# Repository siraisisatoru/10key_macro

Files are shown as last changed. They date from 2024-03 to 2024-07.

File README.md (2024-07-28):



# 10key_macro

A DIY project building an Arduino-based macro keyboard with a 4-bit switch and rotary encoder.

# Background

<!-- The reason for creating this project/ -->
<!-- the why this project is important -->

A number of years ago, I used to learn PIC18 microcontroller and programming using `assembly language`. One of the concepts is using a polling technique to get the button response. Since then I have conducted deep research into designing customized keyboards. Despite there being a huge number of existing projects on the internet, I did want to implement them myself.

# Description

<!-- Describe what it is and what it is included -->

This project mainly consists of four parts. Circuit design, enclosure design, Arduino coding, Python coding.

1. Circuit design

The circuit schematic was built on the EasyEDA platform and is now being ported to KiCAD.



The circuit consists of a microcontroller, 10 cherry keys with 2812 LEDs, an IC74165, an EEPROM AT24C64, a rotary encoder and a 4-bit toggle switch.

By following the schematic, the main circuit was built on a proof board and connected to keys and LEDs through wires.

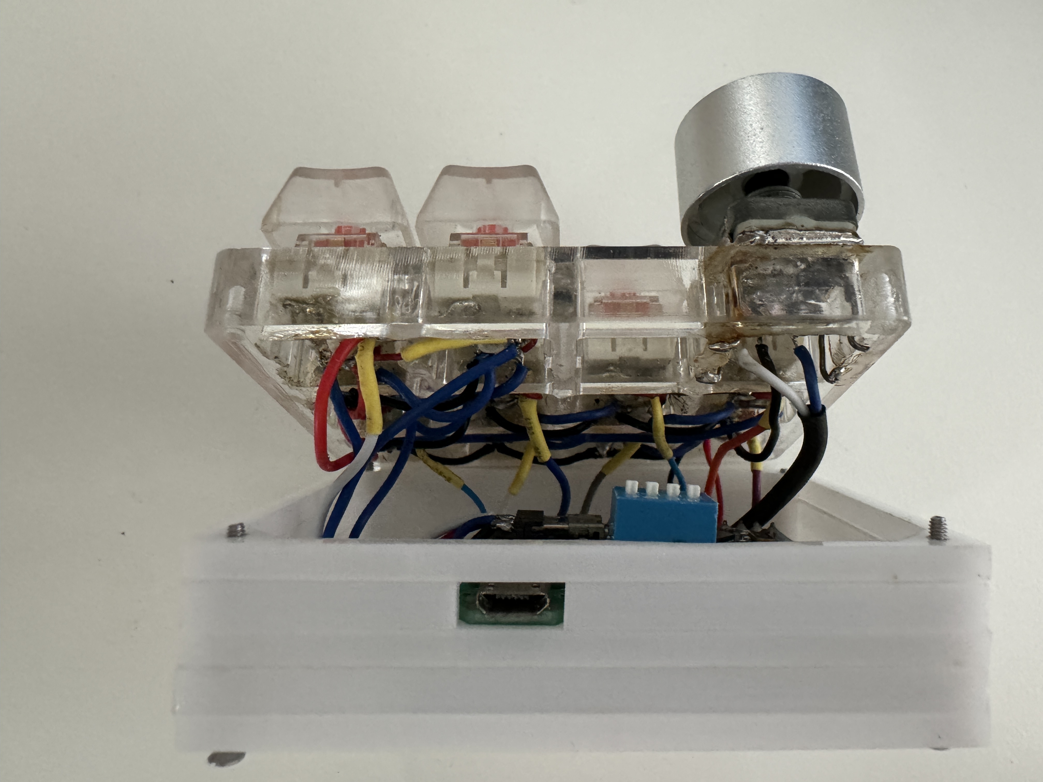
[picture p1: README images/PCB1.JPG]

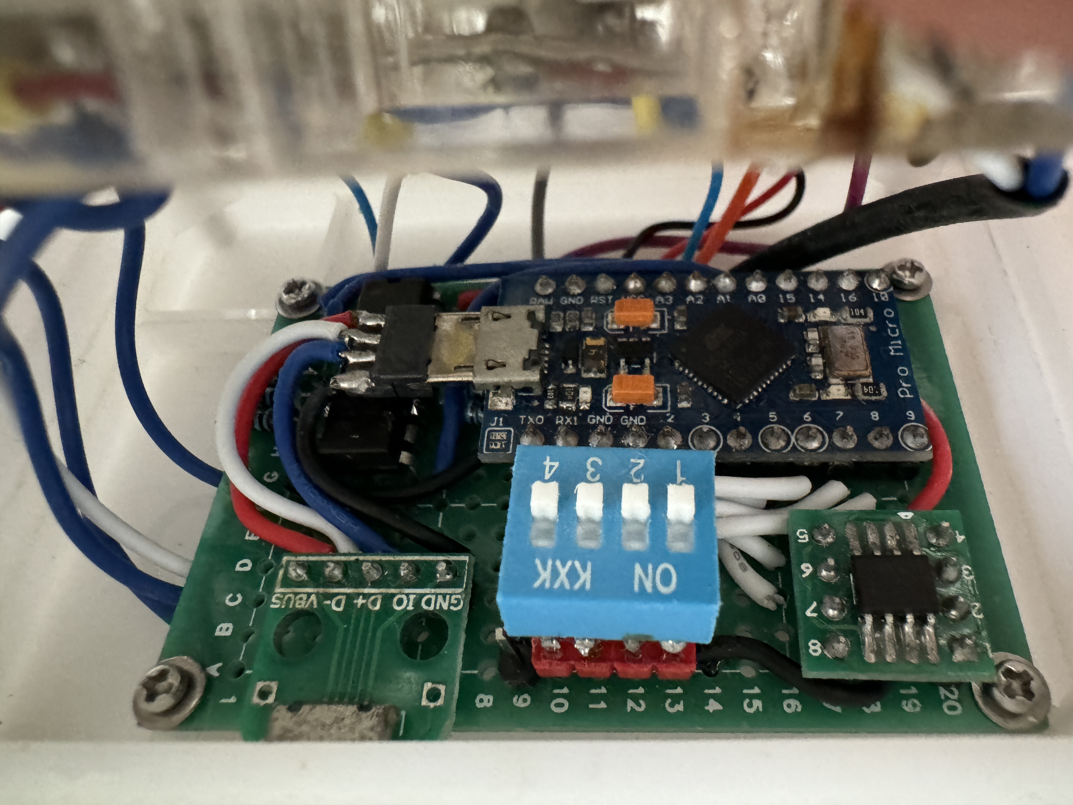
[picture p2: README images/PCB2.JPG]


2. Enclosure design

The enclosure is designed for multiple layers of 4.5mm and 4mm acrylic. The enclosure however begins to fall apart due to aging. A 3D-printed version designed will be reproduced later.

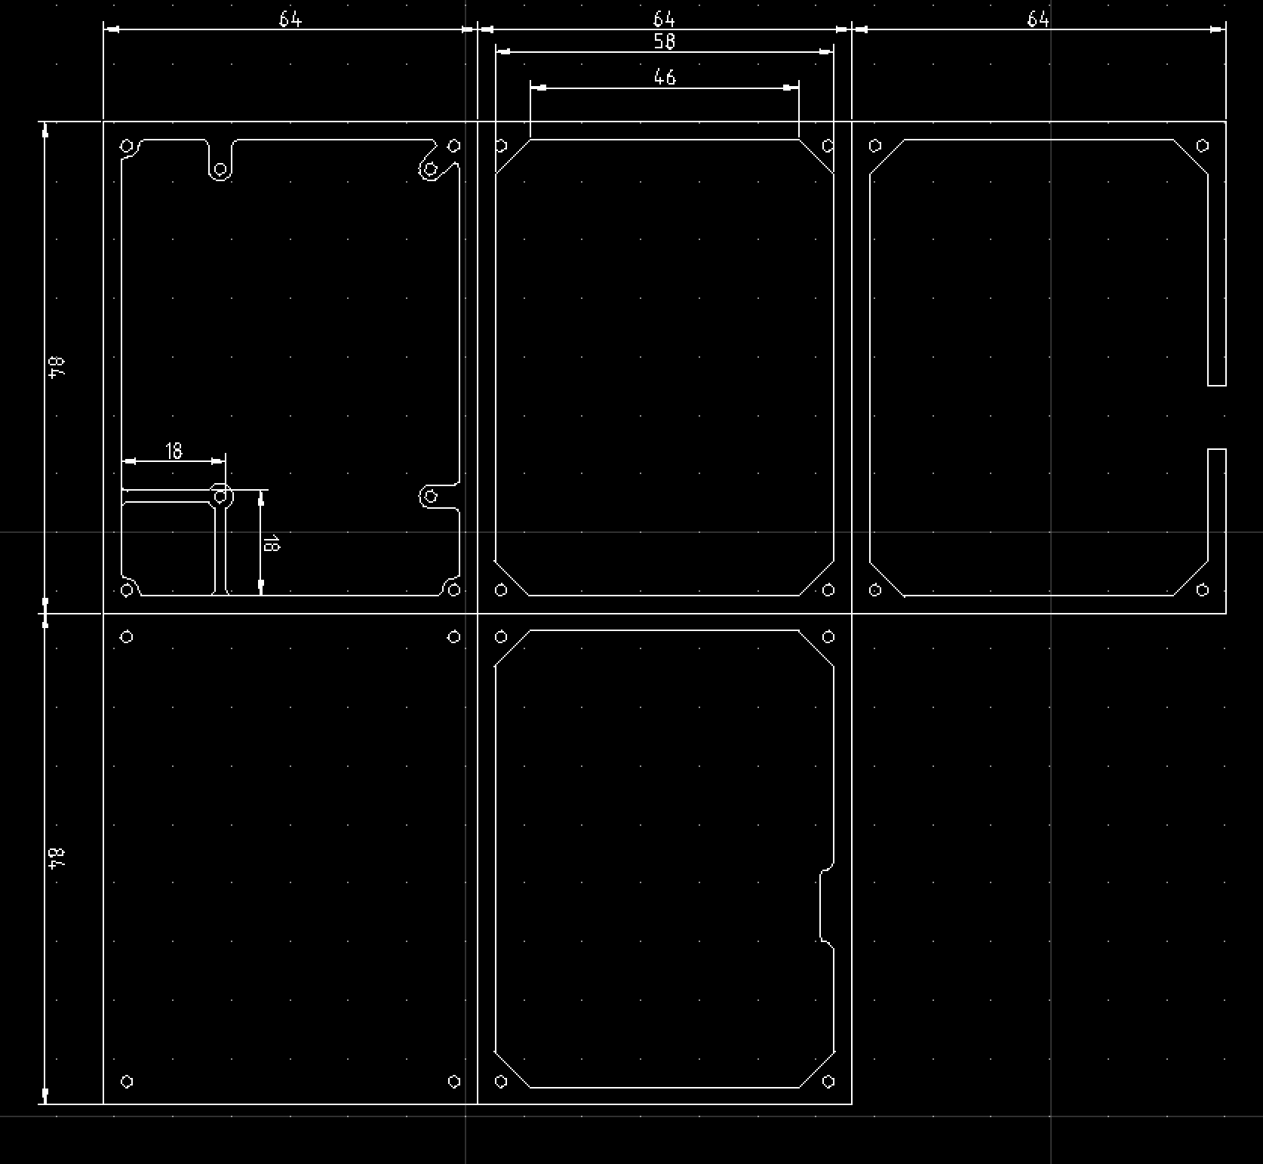
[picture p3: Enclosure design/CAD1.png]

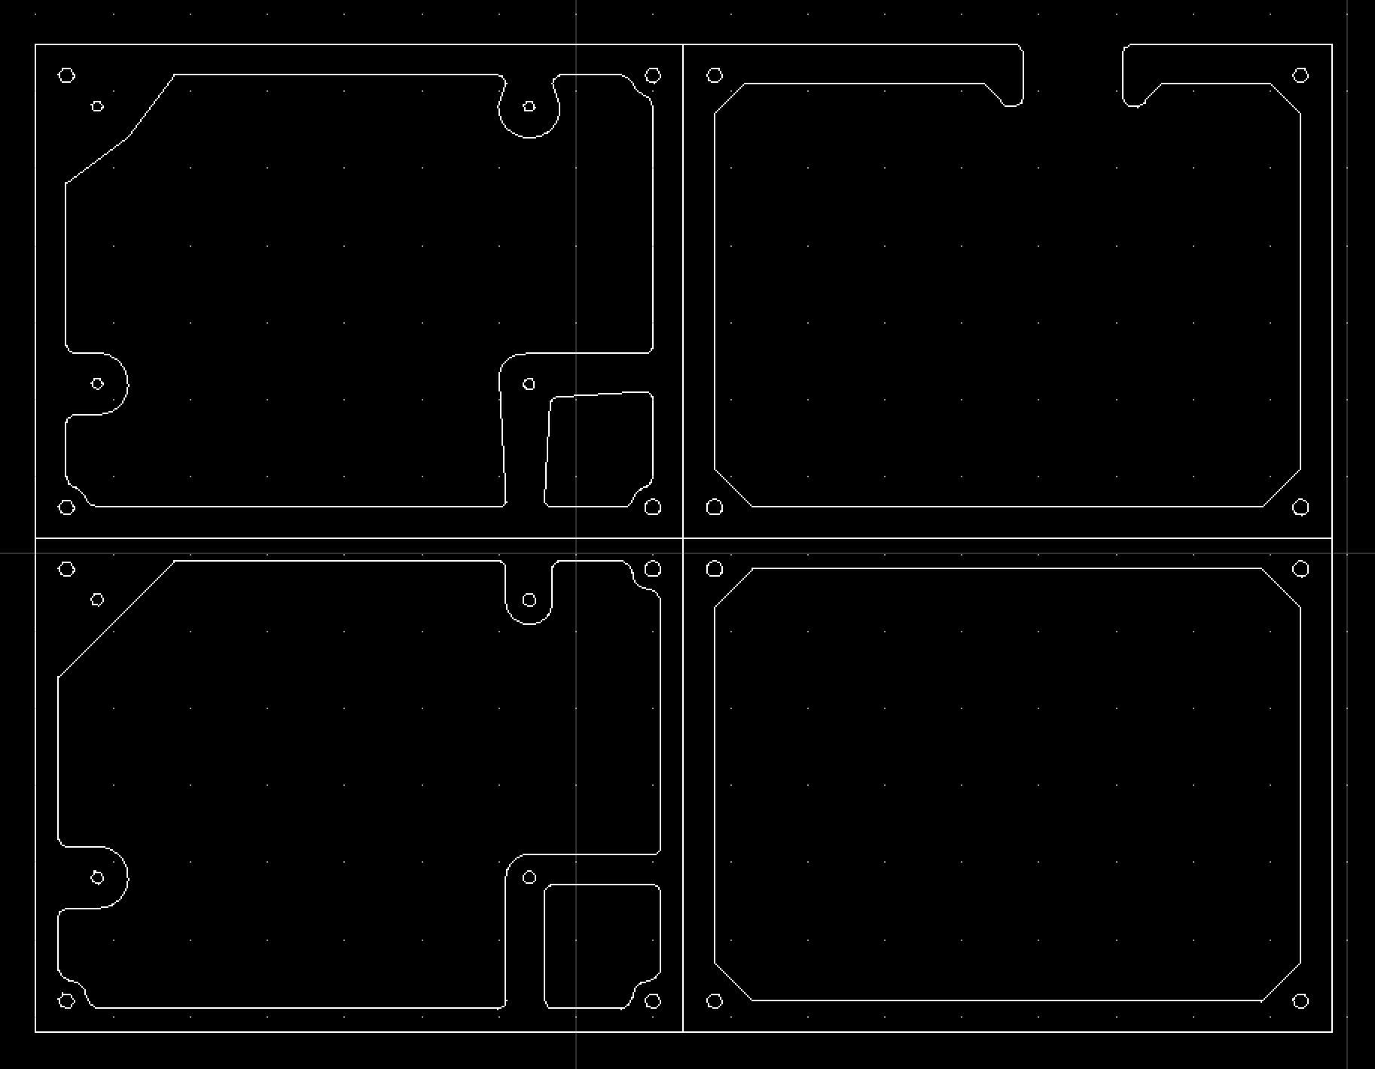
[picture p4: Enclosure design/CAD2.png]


3. Arduino coding

The fundamental idea of the Arduino code design is framing. There are two parts of the Arduino code structure, `setup` and `loop`. I initialize all objects as well as pin I/O in `setup` section; and perform LED and key checks in the loop.

```mermaid
flowchart TD

    subgraph setup
        direction LR

        A[Create objects]-->B[`memMaster` and <br> `panelMaster` init]
        B --> C[Begin initialise <br> keyboard ]
        C --> D[Add rotary encoder <br> to interrupts]
        D --> E[Wait for Serial port]
        E --> E
        E --> F[Wellcome loop]
    end

    subgraph loop
        direction LR

        G[State switch]

        G --> H[state 0]
        G --> I[state 1-8]
        G --> J[state 13]
        G --> K[state 14]
        G --> L[state 15]

        H-->M[LEDShowTick]
        M-->S

        I-->N[monitorKeys]
        N-->O[LEDShowTick]
        O-->S

        J-->P[flush EEPROM]
        P-->S

        K-->Q[print EEPROM]
        Q-->S

        L-->R[load EEPROM <br> from python]
        R-->S

        S[check state and <br> update key config]-->G

    end
    setup --> loop
```

The state is determined by the toggle switch which is capable of 16 values (0 -> 15) and additional functions can be added through the addition of new cases to the `switch`.

| swich pattern | code | feature | description |
| :---: | :--: | :---: | :---: |
| 0000 |  0 | LED display | Complete LED loop through all supported LED effects |
| 0001 |  1 | mode 1 | |
| 0010 |  2 | mode 2 | |
| 0011 |  3 | mode 3 | |
| 0100 |  4 | mode 4 | |
| 0101 |  5 | mode 5 | |
| 0110 |  6 | mode 6 | |
| 0111 |  7 | mode 7 | |
| 1000 |  8 | mode 8 | |
| 1101 |  13  | Flush EEPROM <br> (need to modify Arduino code) | Replace all values in the EEPROm by 0xFF |
| 1110 |  14  | Print Key map | Automatically print whole EEPROM content <br> `-` represents 0xFF |
| 1111 |  15  | Load key map from PC | Enter this mode, use Python to pass mapping json to Arduino |

4. Python coding

To configure each key output in each mode, a predefined JSON file is created and can be loaded to EEPROM. Arduino will load the specific chunk from EEPROM to update each key config.

| Key in object | Description | Example |
| :---: | :---: | :---: |
| Mode | `"mode-xxxx"` <br> where xxxx is the binary representation of the state | `"mode-0001"` |
| Key index | From `"0"` to `"9"` represents the key index of the keyboard | `"0"` |
| default string `"str"` | `"mx string test - y"` where x is the mode from `1` to `8` and <br> y is the key index | `"m1 string test - 1"` |
| default key <br> binding list `"list"` | The list of keybinding that will be `pressed` all in once | `["KEY_LEFT_GUI", "r", null]` |
| default key mode `"mode"` | `1` means print string, `0` means press key binding in the list and `2` means press and hold | `1` |

<details>
<summary> Default configuration JSON file</summary>

```json
{
    "mode-0001": {
        "0": {
            "str": "m1 string test - 0, intentionally make a long string for testing",
            "list": ["KEY_DELETE", null, null],
            "mode": 1
        },
        "1": {
            "str": "m1 string test - 1",
            "list": ["KEY_LEFT_GUI", "r", null],
            "mode": 0
        },
        "2": {
            "str": "m1 string test - 2",
            "list": ["KEY_DELETE", null, null],
            "mode": 0
        },
        "3": {
            "str": "m1 string test - 3",
            "list": [null, null, null],
            "mode": 1
        },
        "4": {
            "str": "m1 string test - 4",
            "list": [null, null, null],
            "mode": 1
        },
        "5": {
            "str": "m1 string test - 5",
            "list": [null, null, null],
            "mode": 1
        },
        "6": {
            "str": "m1 string test - 6",
            "list": [null, null, null],
            "mode": 1
        },
        "7": {
            "str": "m1 string test - 7",
            "list": [null, null, null],
            "mode": 1
        },
        "8": {
            "str": "m1 string test - 8",
            "list": [null, null, null],
            "mode": 1
        },
        "9": {
            "str": "m1 string test - 9",
            "list": [null, null, null],
            "mode": 1
        }
    },
    "mode-0010": {
        "0": {
            "str": "",
            "list": [null, null, null],
            "mode": 2
        },
        "1": {
            "str": "m2 string test - 1",
            "list": [null, null, null],
            "mode": 0
        },
        "2": {
            "str": "m2 string test - 2",
            "list": ["KEY_LEFT_GUI", "s", null],
            "mode": 2
        },
        "3": {
            "str": "m2 string test - 3",
            "list": ["KEY_LEFT_GUI", "x", null],
            "mode": 0
        },
        "4": {
            "str": "m2 string test - 4",
            "list": ["KEY_LEFT_SHIFT", null, null],
            "mode": 2
        },
        "5": {
            "str": "m2 string test - 5",
            "list": ["KEY_UP_ARROW", null, null],
            "mode": 0
        },
        "6": {
            "str": "m2 string test - 6",
            "list": ["KEY_LEFT_GUI", "f", null],
            "mode": 0
        },
        "7": {
            "str": "m2 string test - 7",
            "list": ["KEY_LEFT_GUI", "v", null],
            "mode": 0
        },
        "8": {
            "str": "m2 string test - 8",
            "list": ["KEY_LEFT_GUI", "c", null],
            "mode": 0
        },
        "9": {
            "str": "m2 string test - 9",
            "list": ["KEY_DOWN_ARROW", null, null],
            "mode": 0
        }
    },
    "mode-0011": {
        "0": {
            "str": "m3 string test - 0",
            "list": [null, null, null],
            "mode": 1
        },
        "1": {
            "str": "m3 string test - 1",
            "list": [null, null, null],
            "mode": 1
        },
        "2": {
            "str": "m3 string test - 2",
            "list": [null, null, null],
            "mode": 1
        },
        "3": {
            "str": "m3 string test - 3",
            "list": [null, null, null],
            "mode": 1
        },
        "4": {
            "str": "m3 string test - 4",
            "list": [null, null, null],
            "mode": 1
        },
        "5": {
            "str": "m3 string test - 5",
            "list": [null, null, null],
            "mode": 1
        },
        "6": {
            "str": "m3 string test - 6",
            "list": [null, null, null],
            "mode": 1
        },
        "7": {
            "str": "m3 string test - 7",
            "list": [null, null, null],
            "mode": 1
        },
        "8": {
            "str": "m3 string test - 8",
            "list": [null, null, null],
            "mode": 1
        },
        "9": {
            "str": "m3 string test - 9",
            "list": [null, null, null],
            "mode": 1
        }
    },
    "mode-0100": {
        "0": {
            "str": "m4 string test - 0",
            "list": [null, null, null],
            "mode": 1
        },
        "1": {
            "str": "m4 string test - 1",
            "list": [null, null, null],
            "mode": 1
        },
        "2": {
            "str": "m4 string test - 2",
            "list": [null, null, null],
            "mode": 1
        },
        "3": {
            "str": "m4 string test - 3",
            "list": [null, null, null],
            "mode": 1
        },
        "4": {
            "str": "m4 string test - 4",
            "list": [null, null, null],
            "mode": 1
        },
        "5": {
            "str": "m4 string test - 5",
            "list": [null, null, null],
            "mode": 1
        },
        "6": {
            "str": "m4 string test - 6",
            "list": [null, null, null],
            "mode": 1
        },
        "7": {
            "str": "m4 string test - 7",
            "list": [null, null, null],
            "mode": 1
        },
        "8": {
            "str": "m4 string test - 8",
            "list": [null, null, null],
            "mode": 1
        },
        "9": {
            "str": "m4 string test - 9",
            "list": [null, null, null],
            "mode": 1
        }
    },
    "mode-0101": {
        "0": {
            "str": "m5 string test - 0",
            "list": [null, null, null],
            "mode": 1
        },
        "1": {
            "str": "m5 string test - 1",
            "list": [null, null, null],
            "mode": 1
        },
        "2": {
            "str": "m5 string test - 2",
            "list": [null, null, null],
            "mode": 1
        },
        "3": {
            "str": "m5 string test - 3",
            "list": [null, null, null],
            "mode": 1
        },
        "4": {
            "str": "m5 string test - 4",
            "list": [null, null, null],
            "mode": 1
        },
        "5": {
            "str": "m5 string test - 5",
            "list": [null, null, null],
            "mode": 1
        },
        "6": {
            "str": "m5 string test - 6",
            "list": [null, null, null],
            "mode": 1
        },
        "7": {
            "str": "m5 string test - 7",
            "list": [null, null, null],
            "mode": 1
        },
        "8": {
            "str": "m5 string test - 8",
            "list": [null, null, null],
            "mode": 1
        },
        "9": {
            "str": "m5 string test - 9",
            "list": [null, null, null],
            "mode": 1
        }
    },
    "mode-0110": {
        "0": {
            "str": "m6 string test - 0",
            "list": [null, null, null],
            "mode": 1
        },
        "1": {
            "str": "m6 string test - 1",
            "list": [null, null, null],
            "mode": 1
        },
        "2": {
            "str": "m6 string test - 2",
            "list": [null, null, null],
            "mode": 1
        },
        "3": {
            "str": "m6 string test - 3",
            "list": [null, null, null],
            "mode": 1
        },
        "4": {
            "str": "m6 string test - 4",
            "list": [null, null, null],
            "mode": 1
        },
        "5": {
            "str": "m6 string test - 5",
            "list": [null, null, null],
            "mode": 1
        },
        "6": {
            "str": "m6 string test - 6",
            "list": [null, null, null],
            "mode": 1
        },
        "7": {
            "str": "m6 string test - 7",
            "list": [null, null, null],
            "mode": 1
        },
        "8": {
            "str": "m6 string test - 8",
            "list": [null, null, null],
            "mode": 1
        },
        "9": {
            "str": "m6 string test - 9",
            "list": [null, null, null],
            "mode": 1
        }
    },
    "mode-0111": {
        "0": {
            "str": "m7 string test - 0",
            "list": [null, null, null],
            "mode": 1
        },
        "1": {
            "str": "m7 string test - 1",
            "list": [null, null, null],
            "mode": 1
        },
        "2": {
            "str": "m7 string test - 2",
            "list": [null, null, null],
            "mode": 1
        },
        "3": {
            "str": "m7 string test - 3",
            "list": [null, null, null],
            "mode": 1
        },
        "4": {
            "str": "m7 string test - 4",
            "list": [null, null, null],
            "mode": 1
        },
        "5": {
            "str": "m7 string test - 5",
            "list": [null, null, null],
            "mode": 1
        },
        "6": {
            "str": "m7 string test - 6",
            "list": [null, null, null],
            "mode": 1
        },
        "7": {
            "str": "m7 string test - 7",
            "list": [null, null, null],
            "mode": 1
        },
        "8": {
            "str": "m7 string test - 8",
            "list": [null, null, null],
            "mode": 1
        },
        "9": {
            "str": "m7 string test - 9",
            "list": [null, null, null],
            "mode": 1
        }
    },
    "mode-1000": {
        "0": {
            "str": "m8 string test - 0",
            "list": [null, null, null],
            "mode": 1
        },
        "1": {
            "str": "m8 string test - 1",
            "list": [null, null, null],
            "mode": 1
        },
        "2": {
            "str": "m8 string test - 2",
            "list": [null, null, null],
            "mode": 1
        },
        "3": {
            "str": "m8 string test - 3",
            "list": [null, null, null],
            "mode": 1
        },
        "4": {
            "str": "m8 string test - 4",
            "list": [null, null, null],
            "mode": 1
        },
        "5": {
            "str": "m8 string test - 5",
            "list": [null, null, null],
            "mode": 1
        },
        "6": {
            "str": "m8 string test - 6",
            "list": [null, null, null],
            "mode": 1
        },
        "7": {
            "str": "m8 string test - 7",
            "list": [null, null, null],
            "mode": 1
        },
        "8": {
            "str": "m8 string test - 8",
            "list": [null, null, null],
            "mode": 1
        },
        "9": {
            "str": "m8 string test - 9",
            "list": [null, null, null],
            "mode": 1
        }
    }
}
```

</details>

By default, the Arduino keyboard library accepts a one-byte character that represents the key on a modern keyboard. The Python program can convert the special character into that one-byte character.

<details>
<summary>Arduino Keyboard library key code JSON file</summary>

```json
{
    "KEY_LEFT_CTRL": "0x80",
    "KEY_LEFT_SHIFT": "0x81",
    "KEY_LEFT_ALT": "0x82",
    "KEY_LEFT_GUI": "0x83",
    "KEY_RIGHT_CTRL": "0x84",
    "KEY_RIGHT_SHIFT": "0x85",
    "KEY_RIGHT_ALT": "0x86",
    "KEY_RIGHT_GUI": "0x87",

    "KEY_UP_ARROW": "0xDA",
    "KEY_DOWN_ARROW": "0xD9",
    "KEY_LEFT_ARROW": "0xD8",
    "KEY_RIGHT_ARROW": "0xD7",
    "KEY_BACKSPACE": "0xB2",
    "KEY_TAB": "0xB3",
    "KEY_RETURN": "0xB0",
    "KEY_MENU": "0xED",
    "KEY_ESC": "0xB1",
    "KEY_INSERT": "0xD1",
    "KEY_DELETE": "0xD4",
    "KEY_PAGE_UP": "0xD3",
    "KEY_PAGE_DOWN": "0xD6",
    "KEY_HOME": "0xD2",
    "KEY_END": "0xD5",
    "KEY_CAPS_LOCK": "0xC1",
    "KEY_PRINT_SCREEN": "0xCE",
    "KEY_SCROLL_LOCK": "0xCF",
    "KEY_PAUSE": "0xD0",

    "KEY_NUM_LOCK": "0xDB",
    "KEY_KP_SLASH": "0xDC",
    "KEY_KP_ASTERISK": "0xDD",
    "KEY_KP_MINUS": "0xDE",
    "KEY_KP_PLUS": "0xDF",
    "KEY_KP_ENTER": "0xE0",
    "KEY_KP_1": "0xE1",
    "KEY_KP_2": "0xE2",
    "KEY_KP_3": "0xE3",
    "KEY_KP_4": "0xE4",
    "KEY_KP_5": "0xE5",
    "KEY_KP_6": "0xE6",
    "KEY_KP_7": "0xE7",
    "KEY_KP_8": "0xE8",
    "KEY_KP_9": "0xE9",
    "KEY_KP_0": "0xEA",
    "KEY_KP_DOT": "0xEB",

    "KEY_F1": "0xC2",
    "KEY_F2": "0xC3",
    "KEY_F3": "0xC4",
    "KEY_F4": "0xC5",
    "KEY_F5": "0xC6",
    "KEY_F6": "0xC7",
    "KEY_F7": "0xC8",
    "KEY_F8": "0xC9",
    "KEY_F9": "0xCA",
    "KEY_F10": "0xCB",
    "KEY_F11": "0xCC",
    "KEY_F12": "0xCD",
    "KEY_F13": "0xF0",
    "KEY_F14": "0xF1",
    "KEY_F15": "0xF2",
    "KEY_F16": "0xF3",
    "KEY_F17": "0xF4",
    "KEY_F18": "0xF5",
    "KEY_F19": "0xF6",
    "KEY_F20": "0xF7",
    "KEY_F21": "0xF8",
    "KEY_F22": "0xF9",
    "KEY_F23": "0xFA",
    "KEY_F24": "0xFB"
}
```

</details>

# Use of this project

This project is a user-friendly design and is highly customizable. By modifying the configuration JSON file, users can now have 80 individually defined shortcut keys.

## Build the keyboard

To build the keyboard, you will need the following electronic components.

| Index | Item | Quantity  |
| :---: | :---: | :---: |
| 1 | 2812 LEDs and capacitor (100nF) | 10 |
| 2 | Cherry keys | 10 |
| 3 | IC74165 | 1 |
| 4 | AT24C64 | 1 |
| 5 | Rotary encoder | 1 |
| 6 | 4-bit toggle switch | 1 |
| 7 | Arduino Pro Micro | 1 |
| 8 | 10k resistor | 9 |
| 9 | Micro usb female and male header |  1 each |
|  10 | Suitable capacitor at Arduino's 5V output and GND | 1 |
|  11 | 3D printed or acrylic enclosure, <br> 10 key acrylic testing frame | 1 |
|  12 | M3 screws long (4 cm) and short (0.5 cm) |  4 each |
|  13 | Jumper wires, soldering wire and proof board | As needed |

## Load JSON to EEPROM

Once finish building the board, you can load the Arduino code to the board and get ready to write the JSON file to the EEPROM.

Install the required library for Python code.

```sh
pip install pyserial
pip install inputimeout
```

1. Load the Arduino code to the board.
2. Toggle the switch to `1111` position and unplug the board from the PC.
3. Turn off all terminals on the PC.
4. Plug in the board.
5. Execute the Python code and select the correct port.

The Python code will automatically detect the Arduino is looking for the JSON and dump the data through the Serial port.

# Upcoming updates

Some minor improvements to this project may or may not be updated.

-   [ ] Add manual LED effect sequence that allows different LED patterns for different state
-   [ ] Update 3D model

# Used libraries

This project consisted of several open-source projects. This section aims to acknowledge them to make this project possible.

-   [WS2812](https://github.com/cpldcpu/light_ws2812)

-   [RotaryEncoder](https://github.com/mathertel/RotaryEncoder/)

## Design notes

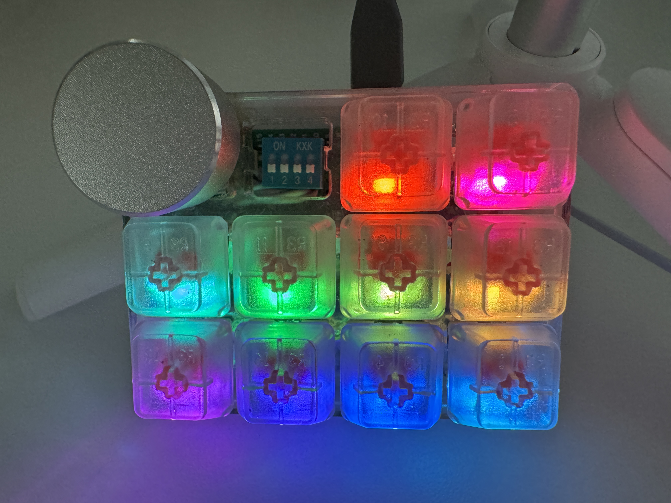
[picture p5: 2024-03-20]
README images/demo1.JPG

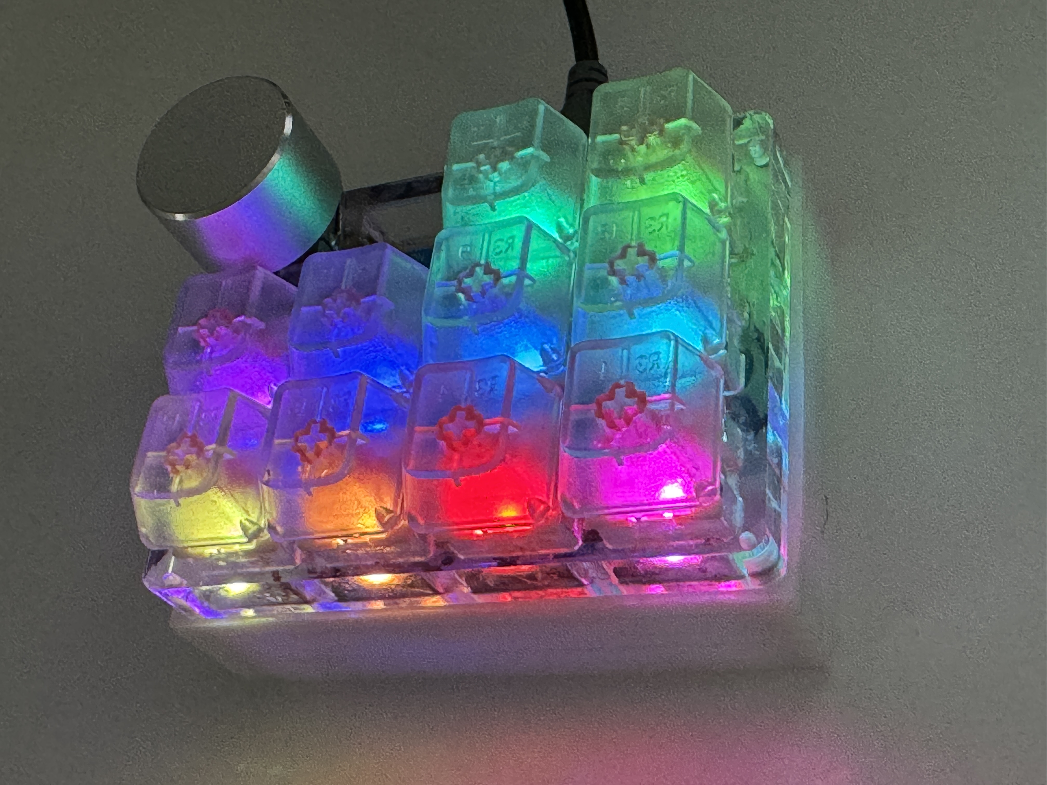
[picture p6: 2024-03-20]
README images/demo2.JPG

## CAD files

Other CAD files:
Enclosure design/10 key 4.5mm_backup.dwg
Enclosure design/10 key 4mm.dwg

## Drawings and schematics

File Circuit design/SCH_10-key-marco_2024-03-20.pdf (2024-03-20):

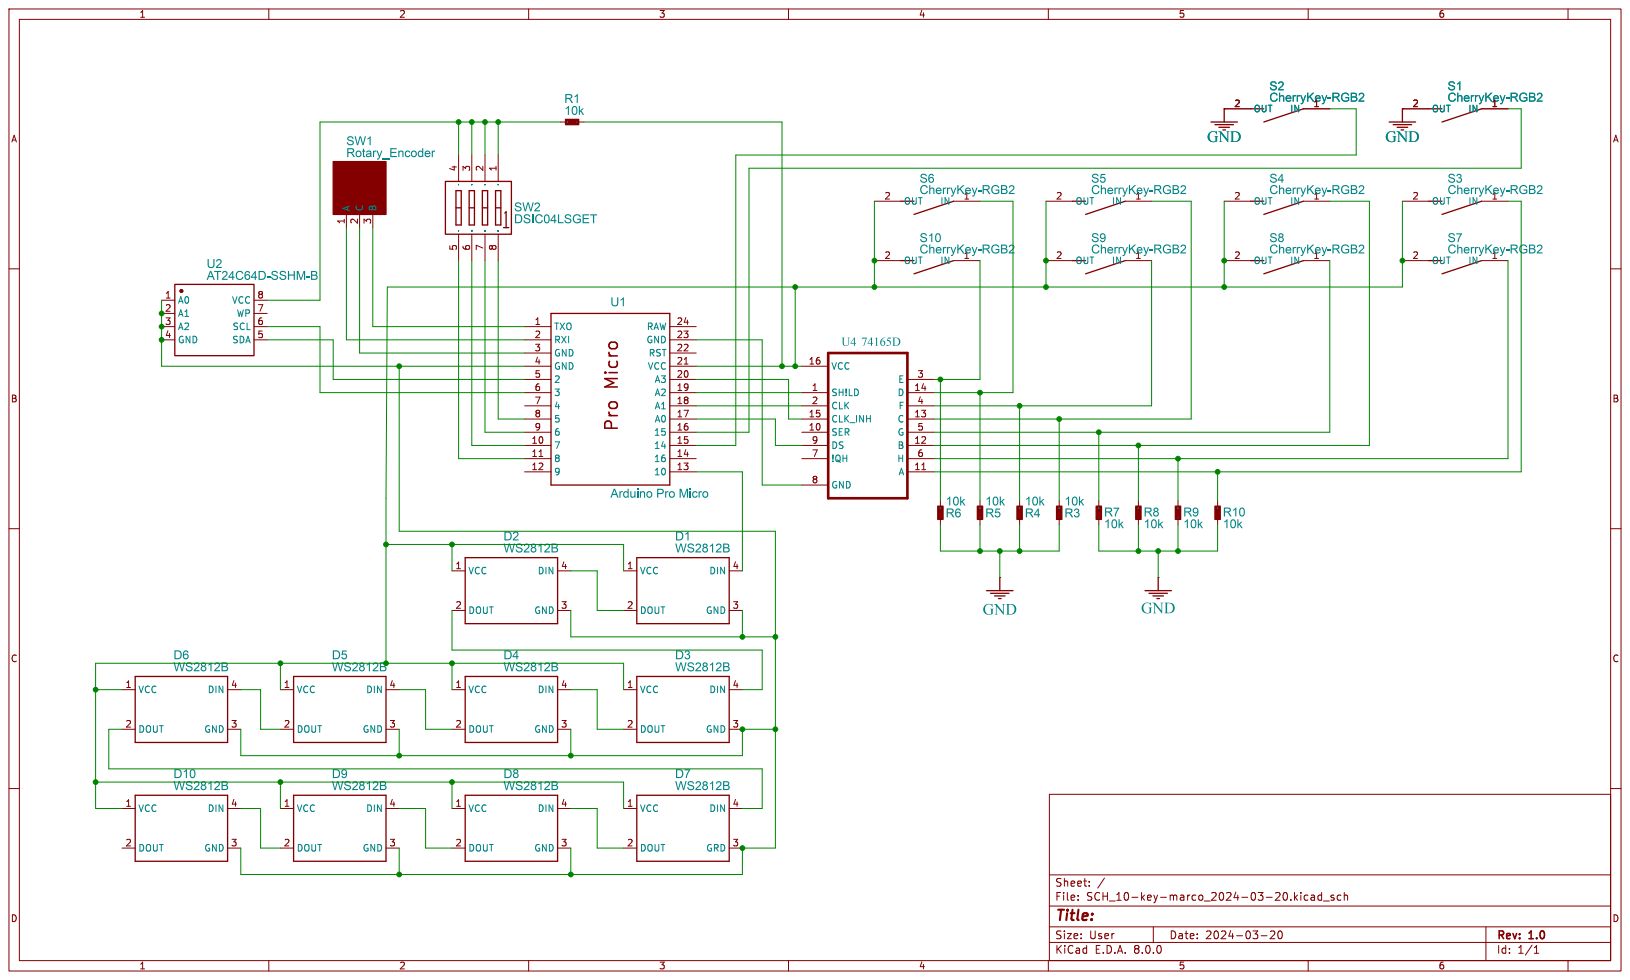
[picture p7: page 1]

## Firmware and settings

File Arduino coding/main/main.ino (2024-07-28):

#include "Arduino.h"
#include "src/memManager/memManager.h"
#include "src/panel/panel.h"

panel panelMaster;    // declare control panel master
memManager memMaster; // declare memory control panel master
byte state;

void setup() {

    Serial.begin(115200);

    // init panel
    state = 0b1111 - panelMaster.getState();
    memMaster.init(state);
    panelMaster.init(memMaster.getKeyConfig());
    panelMaster.beginKeyboard();
    panelMaster.beginMouse();
    panelMaster.attachInterruptToEncoder(rencoderP1);
    panelMaster.attachInterruptToEncoder(rencoderP2);

    unsigned long now = millis();
    while (!Serial) {
        if (millis() - now > 3000) {
            panelMaster.errorLoop();
            break;
        }
    }

    panelMaster.wellcomeLoop();
}

void loop() {

    switch (state) {
    case 0:
        panelMaster.LEDShowTick(state);
        break;
    case 1:
    case 2:
    case 3:
    case 4:
    case 5:
    case 6:
    case 7:
    case 8:
        // Serial.println("Ordinary");
        panelMaster.monitorKeys();
        panelMaster.LEDShowTick(state);
        break;

    case 13:

        Serial.println("Flushing EEPROM...");
        Serial.println("!! You are about to erase the whole EEPROM !!");
        Serial.println("!!!!!!! This process is irreversible !!!!!!!!");
        // Uncomment thie following line to enable this feature.

        // memMaster.flushEEPROM();
        Serial.println("Exit flushing EEPROM.\n\tFlip the switch to other states.");

        while ((0b1111 - panelMaster.getState()) == 13) {
            /* can add LED effect */
            delay(5);
        }
        break;
    case 14:
        // if (!Serial) {
        //     break;
        // }
        Serial.println("Print EEPROM...");
        memMaster.printEEPROM();
        Serial.println("Exit print EEPROM.\n\tFlip the switch to other states.");

        while ((0b1111 - panelMaster.getState()) == 14) {
            /* can add LED effect */
            delay(5);
        }
        break;
    case 15:
        // if (!Serial) {
        //     break;
        // }
        Serial.println("Begin load json from PC...");
        unsigned long now = millis();

        unsigned int addr = 0;
        unsigned char size = 0;

        while (1) {
            if ((millis() - now > 10000) && (addr == 0)) {
                break;
            }
            if ((millis() - now > 60000) && (addr != 0)) {
                Serial.println("Fail loadinding within 1 min.\nExist for timeout.");
                break;
            }

            String receiveData = Serial.readStringUntil('\n');

            for (int i = 0; i < receiveData.length(); i++) {
                receiveData.setCharAt(i, byte(receiveData.charAt(i) & 0xFF));
                Serial.print(byte(receiveData.charAt(i) & 0xFF), HEX);
                Serial.print(" ");
            }
            Serial.print(receiveData.length());
            Serial.println();

            if (receiveData) {
                if (receiveData == "done!")
                    break;
                if (receiveData.indexOf("Addr") > -1) {
                    addr = receiveData.substring(6).toInt(); // Skip "Addr: "
                    continue;
                } else if (receiveData.indexOf("Size") > -1) {
                    size = receiveData.substring(6).toInt(); // Skip "Size: "
                    memMaster.setSize(size);
                    continue;
                } else {
                    memMaster.writeEEPROM(addr, receiveData);
                    addr += size;
                }
            }
        }

        Serial.println("Exit load json from PC.\n\tFlip the switch to other states.");
        while ((0b1111 - panelMaster.getState()) == 15) {
            /* can add LED effect */
            delay(5);
        }
        break;
    default:
        break;
    }

    if (state != (0b1111 - panelMaster.getState())) {
        state = 0b1111 - panelMaster.getState();
        memMaster.loadKeyConfig(state);
        panelMaster.updateKeys(memMaster.getKeyConfig());
    }
}

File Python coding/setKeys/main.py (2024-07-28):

# python3.11 main.py
# from inputimeout import inputimeout, TimeoutOccurred
import serial.tools.list_ports
import json
import time
from datetime import datetime

_print = print


def print(*args, **kw):
    _print("[%s]" % (datetime.now()), *args, **kw)


BAUD_RATE = 115200
KEY_CHUNK_SIZE = 40


def send_json_to_arduino(comPort):
    keyMapPath = "keyMap.json"
    keyCodePath = "keyCode.json"
    # Open serial port
    ser = serial.Serial(comPort, BAUD_RATE, timeout=1)
    time.sleep(2)  # Wait for the Arduino to reset after establishing serial connection

    # Open the JSON file and load its contents
    with open(keyMapPath, "r") as file:
        keyMapJson = json.load(file)

    with open(keyCodePath, "r") as file:
        keyCodeJson = json.load(file)

    ser.write(f"Size: {KEY_CHUNK_SIZE}\n".encode())

    for i in range(1, 9):

        memAddr = (i - 1) * (KEY_CHUNK_SIZE) * 10
        ser.write(f"Addr: {memAddr}\n".encode())

        modeIdx = format(i, "04b")
        # print(modeIdx)
        keyMap = keyMapJson["mode-" + modeIdx]

        for keyIdx in range(10):
            # keyMode = "1" if keyMap[str(keyIdx)]["mode"] else "0"
            keyMode = str(keyMap[str(keyIdx)]["mode"])
            ser.write(keyMode.encode())

            stringArr = ""
            # print(keyMap[str(keyIdx)])
            """
                - define max str length 26 byte
                - define list length 3  byte
                - one byte for mode
                => 30 bytes for a key in a mode
            """

            packet = bytearray()
            for keyBind in keyMap[str(keyIdx)]["list"]:
                # here assign keyBinds, need to map with actural key code
                if keyBind in keyCodeJson:
                    print("Found special key -> ", end="")
                    print(keyBind)
                    # safeKeybind = ''
                    packet.append(int(keyCodeJson[keyBind], 16))

                elif keyBind == None:
                    packet.append(ord("\xFF"))
                else:
                    packet.append(ord(keyBind))

            ser.write(packet)

            stringArr = keyMap[str(keyIdx)]["str"]
            # print(len(stringArr))
            if len(stringArr) > ((KEY_CHUNK_SIZE - 4)):
                stringArr = stringArr[0 : ((KEY_CHUNK_SIZE - 4))]
            elif len(stringArr) < ((KEY_CHUNK_SIZE - 4)):
                stringArr = f"{stringArr:<{(KEY_CHUNK_SIZE - 4)}}"

            ser.write(stringArr.encode())
            ser.write("\n".encode())

        # print(memAddr)
        # print(dataChunk)
        # print('done dataChunk')

        # Convert JSON data to string and send it to Arduino
        # for data in dataChunk:
        # ser.write(f"{data}\n".encode())

    ser.write("done!".encode())
    # Close serial port
    ser.close()
    print("JSON data sent successfully!")


def select_serial_port():
    # Get a list of available serial ports
    ports = serial.tools.list_ports.comports()

    # Print the list of available ports
    print("Available serial ports:")
    for index, port in enumerate(ports, start=1):
        print(f"{index}. {port.device}")

    # Prompt the user to select a port
    while True:
        try:
            selection = int(
                input("Enter the number corresponding to the desired port: ")
            )
            if 1 <= selection <= len(ports):
                selected_port = ports[selection - 1].device
                print(f"Selected port: {selected_port}")
                return selected_port
            else:
                print("Invalid selection. Please enter a valid number.")
        except ValueError:
            print("Invalid input. Please enter a number.")


if __name__ == "__main__":
    selected_port = select_serial_port()

    # Open the serial port
    ser = serial.Serial(selected_port, BAUD_RATE)

    try:
        # Loop to continuously send data to Arduino and receive response
        while True:
            # Get user input from the Python terminal
            # data_to_send = input("Enter data to send to Arduino: ")
            # Send data to Arduino
            # ser.write(data_to_send.encode())

            # try:
            # c = inputimeout(prompt='hello\n', timeout=0.5)
            # except TimeoutOccurred:
            #     c = 'timeout

            # print(c)

            # Read and print response from Arduino
            response = ser.readline().decode().strip()
            if response:
                print(response)
            if response == "Begin load json from PC...":
                send_json_to_arduino(selected_port)

            """
            Addr: 0
            Addr: 300
            Addr: 600
            Addr: 900
            Addr: 1200
            Addr: 1500
            Addr: 1800
            Addr: 2100
            """

    except KeyboardInterrupt:
        # Close the serial port when the user interrupts the program
        ser.close()
        print("\nSerial port closed.")

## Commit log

2024-03-19 Initial commit. Add Arduino code and Python code 🎉
2024-03-20 add circuit schematic and enclosure design, rearrange file structure
    [10 key 4.5mm_backup.dwg, 10 key 4mm.dwg, SCH_10-key-marco_2024-03-20.kicad_sch]
2024-07-28 add mouse scroll feature to the encoder
